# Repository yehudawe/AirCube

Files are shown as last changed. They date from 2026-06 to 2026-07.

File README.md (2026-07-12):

<p align="center">
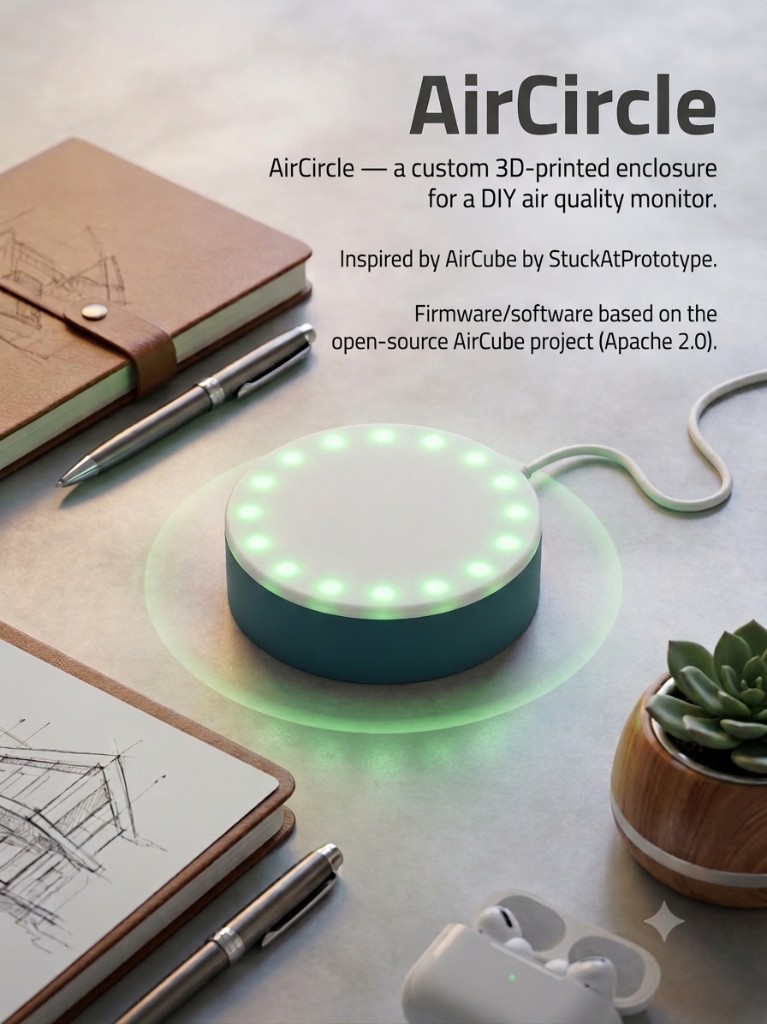
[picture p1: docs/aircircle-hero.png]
AirCircle — a custom 3D-printed DIY air quality monitor
  
</p>

# AirCircle

**A round, glowy DIY air monitor — built from AliExpress parts and a weekend of printing.**

AirCircle is a my remix of [AirCube](https://github.com/StuckAtPrototype/AirCube) by [StuckAtPrototype](https://stuckatprototype.com). Same idea: one LED ring tells you how the air feels, and Zigbee feeds the numbers into Home Assistant. Different hardware: an ESP32-H2 SuperMini, off-the-shelf sensors, and a 3D-printed puck you can build yourself.

This is a **personal fork**, not the official AirCube. Think of it as the breadboard cousin of the real thing — a bit scrappier, still pretty handy on a desk.

| | |
|---|---|
| **Printables** | [AirCircle enclosure STLs](https://www.printables.com/model/1779452-aircircle-diy-air-quality-monitor-enclosure) |
| **Upstream project** | [StuckAtPrototype/AirCube](https://github.com/StuckAtPrototype/AirCube) |
| **License** | [Apache 2.0](LICENSE) |
| **Extra build notes** | [DIY_SUPERMINI.md](DIY_SUPERMINI.md) |

> **Not affiliated with or endorsed by StuckAtPrototype.**

---

## What's in this repo

- **AirCircle enclosure** — a round, snap-together case (`mechanical/air-circle/`)
- **SuperMini firmware** — pin map in `firmware/main/board_config.h`
- **ENS160 + AHT21** sensors (the AliExpress-friendly combo)
- **WS2812 LED ring** on GPIO4 — green when life is good, red when you should open a window
- **Full build guide** — source the parts, print, wire, flash

You still get USB serial readings and **Zigbee / Home Assistant** support from the original AirCube firmware.

---

## What you need

### Electronics

Example AliExpress listings — double-check you pick the right variant:

| Part | Notes | Link |
|---|---|---|
| **ESP32-H2 SuperMini** | Must be the **H2** variant (Zigbee-capable) | [AliExpress](https://a.aliexpress.com/_c4Pyot8F) |
| **ENS160 + AHT21 module** | Combined gas + temperature/humidity sensor | [AliExpress](https://a.aliexpress.com/_c32NbwfH) |
| **WS2812 RGB LED ring** | Match LED count to your ring (e.g. 16-LED) | [AliExpress](https://a.aliexpress.com/_c4Vc3oaj) |

Plus a **USB data cable** for power and flashing.

### Fasteners

| Screw | Used for |
|---|---|
| **M3 × 4** | Sensor module → base |
| **M3 × 6** | ESP32-H2 SuperMini → base (via tab) |
| **M2** (short, for plastic) | LED ring → base *(optional, if the fit is loose)* |

The top cover fastens with screws at the printed mounting points on the base.

### 3D-printed parts

Download the STLs from **[Printables](https://www.printables.com/model/1779452-aircircle-diy-air-quality-monitor-enclosure)** or print from this repo:

| File | Purpose |
|---|---|
| `air_circ_base.stl` | Bottom shell |
| `air_circ_top.stl` | Translucent top cover — this is what makes the glow |
| `air_circ_lock.stl` | Tab — supports the ESP32-H2 in the base |
| `air_circle.stp` | Full assembly source (CAD edits) |

Original StuckAtPrototype enclosure files are in [`mechanical/original/`](mechanical/original/) for reference.

---

## Step 1 — Print the enclosure

1. Slice the three STL files in your slicer of choice.
2. **Material:** PLA or PETG. PETG handles a bit more warmth near the electronics.
3. **Top cover:** translucent or natural filament — that's the whole vibe.
4. **Orientation:** flat on the bed, largest face down. Supports only if your slicer insists.
5. Dry-fit base + top + lock before you start soldering.

Wrong ring size? Scale the STLs or tweak `air_circle.stp`.

---

## Step 2 — Wire and solder

Solder (or tightly twist-and-tape) the connections below before mounting anything in the enclosure. All logic signals are **3.3 V** — don't put 5 V on the sensor data lines or the LED data pin.

| Module pin | Connect to ESP32-H2 SuperMini |
|---|---|
| SDA | **GPIO1** (IO1) |
| SCL | **GPIO0** (IO0) |
| VCC | **3V3** |
| GND | **GND** |
| LED DIN | **GPIO4** (IO4) |
| LED +5V | **5V** (USB) — only if your ring needs 5 V power |
| LED GND | **GND** |

Both ENS160 (`0x52`) and AHT21 (`0x38`) share the same I2C bus.

**Button (GPIO9):** short press cycles brightness, hold **3 seconds** for Zigbee pairing (blue flash).

```
  ENS160+AHT21          ESP32-H2 SuperMini          WS2812 ring
  ─────────────         ──────────────────          ───────────
  SDA  ───────────────► GPIO1
  SCL  ───────────────► GPIO0
  VCC  ───────────────► 3V3
  GND  ───────────────► GND ────────────────────► GND
                        GPIO4 ──────────────────► DIN
                        5V (optional) ──────────► +5V
```

Pins: [`firmware/main/board_config.h`](firmware/main/board_config.h)

Double-check your joints, then trim any excess wire so nothing shorts once everything is packed inside the base.

---

## Step 3 — Assemble the enclosure

<p align="center">
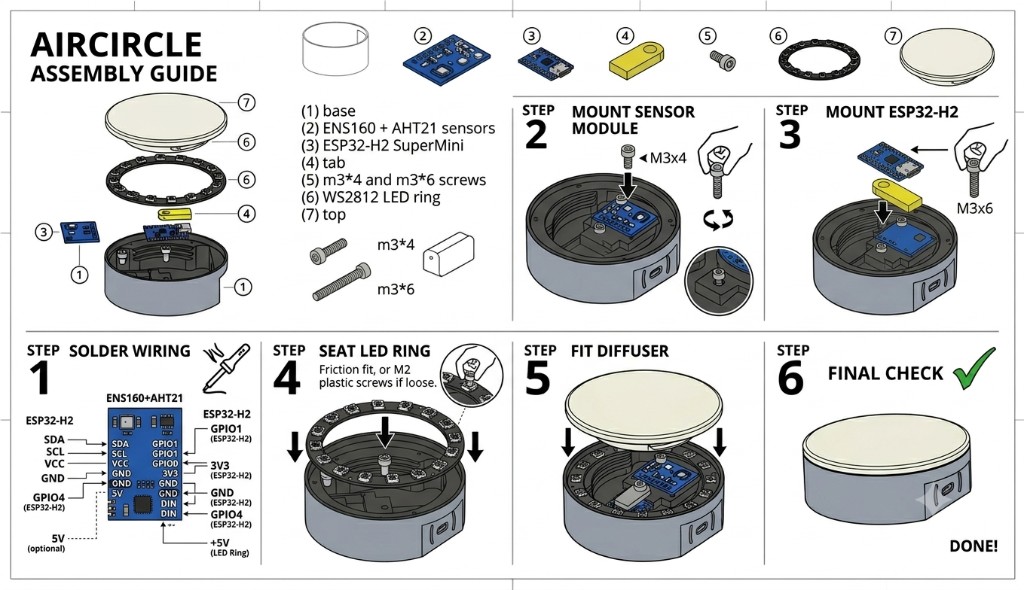
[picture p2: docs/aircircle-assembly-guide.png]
AirCircle assembly guide — wiring, mounting, and final assembly
  
</p>

With the wiring done, mount the parts into the printed base and close it up.

1. **Sensor module** — place the ENS160 + AHT21 board in the base slot and secure it with an **M3 × 4** screw.
2. **Tab + ESP32-H2** — insert the printed tab (`air_circ_lock.stl`) into the base, set the SuperMini on top with the USB-C port lined up to the base cutout, and fasten with an **M3 × 6** screw.
3. **LED ring** — seat the WS2812 ring on the inner rim of the base. A snug print should hold it by friction. If it feels loose, add **small M2 screws for plastic**.
4. **Top cover** — fit the translucent diffuser over the ring and screw it onto the base.

Done — plug in USB, flash if you haven't already, and let it warm up.

> **Tip:** Flash the firmware before screwing on the top cover — USB access and the boot button are much easier to reach.

---

## Step 4 — Configure LED count

Set the LED count to match your ring before building.

Edit [`firmware/main/ws2812_control.h`](firmware/main/ws2812_control.h):

```c
#define NUM_LEDS  16   // change to match your WS2812 ring or strip
```

Default is **30**; a 16-LED ring wants **16**.

---

## Step 5 — Build and flash firmware

Requires [ESP-IDF v5.3+](https://docs.espressif.com/projects/esp-idf/en/latest/esp32h2/get-started/).

```powershell
cd firmware
idf.py set-target esp32h2
idf.py build
idf.py -p COM9 flash monitor
```

Swap `COM9` for your port (`COM*` on Windows, `/dev/tty*` on Linux).

Give it **~3 minutes** after first boot for the ENS160 to warm up — patience, then the readings settle.

### Button controls

| Action | Result |
|---|---|
| Short press | Cycle brightness (off → 10% → 30% → 60% → 100%) |
| Hold 3 seconds | Zigbee pairing mode (blue flash) |

---

## Step 6 — View live readings (optional)

Plug in with a data-capable USB cable:

```powershell
cd scripts
pip install -r requirements.txt
python aircube_app.py
```

Pick your COM port, hit **Connect**, and watch the numbers roll in after warm-up.

---

## Home Assistant (optional)

AirCircle inherits AirCube's **Zigbee** stack. Pair with ZHA or Zigbee2MQTT:

**[HOME_ASSISTANT.md](HOME_ASSISTANT.md)**

Hold the boot button for 3 seconds, enable permit join on your coordinator, and you're in.

---

## How this differs from official AirCube

| | Official AirCube | AirCircle (this repo) |
|---|---|---|
| Board | Custom PCB | ESP32-H2 SuperMini |
| Gas sensor | ENS161 | ENS160 |
| Temp/humidity | ENS210 | AHT21 |
| LED | Onboard WS2812 | External WS2812 ring on GPIO4 |
| Enclosure | StuckAtPrototype design | 3D-printed AirCircle puck |
| BLE BTHome | Supported | Disabled in this fork's defaults |
| AQI-S score | Available over USB serial | Not available (`-1` on ENS160) |

Want the polished commercial version? Head to **[StuckAtPrototype/AirCube](https://github.com/StuckAtPrototype/AirCube)**.

---

## LED colors

The ring runs a smooth green-to-red gradient from **VOC Level** (TVOC-derived):

| LED color | Air quality |
|---|---|
| Green | Good |
| Yellow | Moderate |
| Orange | Poor |
| Red | Time to ventilate |
| Flashing blue | Zigbee pairing |

Full band tables live in the [upstream LED reference](https://github.com/StuckAtPrototype/AirCube/blob/master/README.md#led-reference).

---

## Troubleshooting

**No serial port detected**
- Use a data USB cable, not charge-only.
- Windows: try the [Silicon Labs USB-UART drivers](https://www.silabs.com/developers/usb-to-uart-bridge-vcp-drivers).

**Readings look off right after power-on**
- Normal. ~3 minutes warm-up for the ENS160.

**LED ring wrong or incomplete**
- Check `NUM_LEDS` matches your ring.
- DIN on **GPIO4**, shared GND.

**Zigbee won't pair**
- Hold boot button 3 seconds (blue flash).
- Enable permit join in ZHA or Zigbee2MQTT.
- Move closer to the coordinator.

**Home Assistant missing sensors**
- Load the ZHA quirk or Zigbee2MQTT converter — see [HOME_ASSISTANT.md](HOME_ASSISTANT.md).

---

## Repository layout

```
AirCircle/
├── docs/
│   ├── aircircle-hero.png           # Cover image
│   └── aircircle-assembly-guide.png # Visual assembly guide
├── mechanical/
│   ├── air-circle/          # AirCircle enclosure (STL + STEP)
│   └── original/            # Upstream reference enclosure files
├── firmware/                # Adapted ESP-IDF firmware
│   └── main/
│       ├── board_config.h   # SuperMini pin map
│       └── ws2812_control.h # LED count (NUM_LEDS)
├── scripts/                 # Desktop app for USB serial
├── DIY_SUPERMINI.md         # Supplementary build notes
└── HOME_ASSISTANT.md        # Zigbee setup (from upstream)
```

---

## License and attribution

Based on [AirCube](https://github.com/StuckAtPrototype/AirCube) by StuckAtPrototype, licensed under [Apache 2.0](LICENSE).

AirCircle mechanical files and SuperMini adaptations are shared under the same license. Keep the credit and license when you share or remix.

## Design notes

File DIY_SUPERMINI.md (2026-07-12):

# DIY Build — ESP32-H2 SuperMini

AirCube firmware adapted for breadboard builds with an **ENS160 + AHT21** sensor module and an external **WS2812 LED ring or strip**.

## Parts

Example AliExpress listings for a DIY build (not affiliated with StuckAtPrototype):

| Part | Notes | Link |
|---|---|---|
| **ESP32-H2 SuperMini** | Select the **H2** variant from the listing | [AliExpress](https://a.aliexpress.com/_c4Pyot8F) |
| **ENS160 + AHT21 sensor module** | Combined air-quality and temp/humidity board | [AliExpress](https://a.aliexpress.com/_c32NbwfH) |
| **WS2812 RGB LED ring** | Pick a ring size that fits your enclosure (e.g. 16-LED) | [AliExpress](https://a.aliexpress.com/_c4Vc3oaj) |

You also need a USB cable for power/data. Print the **AirCircle** enclosure from [Printables](https://www.printables.com/model/1779452-aircircle-diy-air-quality-monitor-enclosure) or use the STLs in `mechanical/air-circle/`.

### Fasteners

| Screw | Used for |
|---|---|
| **M3 × 4** | Sensor module → base |
| **M3 × 6** | ESP32-H2 SuperMini → base (via tab) |
| **M2** (short, for plastic) | LED ring → base *(optional)* |

## Wiring and soldering

Solder the connections below before mounting parts in the enclosure.

| Module pin | Connect to ESP32-H2 SuperMini |
|---|---|
| SDA | **GPIO1** (IO1) |
| SCL | **GPIO0** (IO0) |
| VCC | **3V3** |
| GND | **GND** |
| LED DIN | **GPIO4** (IO4) |
| LED +5V | **5V** (USB) if your strip needs 5 V |
| LED GND | **GND** |

Both ENS160 (0x52) and AHT21 (0x38) share the same I2C bus.

**Boot button (GPIO9):** short press cycles LED brightness; hold **3 seconds** for Zigbee pairing (blue flash).

## Assembly

<p align="center">
  AirCircle assembly guide
</p>

1. **Sensor module** — mount in the base with an **M3 × 4** screw.
2. **Tab + ESP32-H2** — insert the printed tab (`air_circ_lock.stl`), place the SuperMini on top (USB-C aligned to the cutout), secure with an **M3 × 6** screw.
3. **LED ring** — seat on the base rim. If the friction fit is loose, use **small M2 screws for plastic**.
4. **Top cover** — fit the diffuser and screw onto the base. Done.

Full step-by-step with printing and flashing: **[README.md](README.md)**.

## LED count

Edit `firmware/main/ws2812_control.h` and change `NUM_LEDS` to match your ring or strip (default **30**; use **16** for a 16-LED ring).

## Build and flash

Requires [ESP-IDF v5.3+](https://docs.espressif.com/projects/esp-idf/en/latest/esp32/get-started/).

```powershell
cd firmware
idf.py set-target esp32h2
idf.py build
idf.py -p COM9 flash monitor
```

## Desktop app

```powershell
cd scripts
pip install -r requirements.txt
python aircube_app.py
```

Select **COM9**, click **Connect** — live temp, humidity, eCO2, TVOC, and VOC Level appear after ~3 minutes warm-up.

## Notes

- **ENS160** is used instead of the official ENS161; AQI-S (relative score) is not available and shows as `-1` over serial.
- **AHT21** replaces the ENS210; temperature/humidity compensation for the gas sensor still works.
- Onboard **GPIO8** WS2812 is unused; the external strip on GPIO4 drives the air-quality color.

Pin definitions live in `firmware/main/board_config.h`.

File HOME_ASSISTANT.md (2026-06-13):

# Connecting AirCube to Home Assistant

This guide walks you through adding your AirCube air quality monitor to Home Assistant over Zigbee. After setup, you'll have live temperature, humidity, eCO2, eTVOC, and VOC Level readings plus a brightness slider in your smart home dashboard.

The AirCube works with both **ZHA** (built-in) and **Zigbee2MQTT**. Pick whichever you already use. If you're starting fresh, ZHA is simpler.

---

## What You Need

- **AirCube** -- powered via USB-C
- **Zigbee coordinator dongle** -- plugs into your Home Assistant machine
- **Home Assistant** -- running on any supported hardware (Raspberry Pi, mini PC, etc.)

### Recommended Zigbee Coordinators

Any Zigbee 3.0 coordinator works. If you don't have one yet, the **SONOFF ZBDongle-E** is the easiest to get started with (~$13).

| Dongle | Notes |
|---|---|
| SONOFF ZBDongle-E | Best value, widely available |
| SONOFF ZBDongle-P | Proven, large community |
| ConBee II / III | Also works, popular alternative |

---

# Method A -- ZHA (Recommended)

Use this method if you're using Home Assistant's built-in **Zigbee Home Automation** integration (the default). No extra add-ons required.

## A1 -- Set Up ZHA

If you already have ZHA running with your coordinator, skip to A2.

1. Plug your Zigbee coordinator dongle into your Home Assistant machine.
2. Go to **Settings > Devices & Services > Add Integration**.
3. Search for **Zigbee Home Automation (ZHA)** and add it.
4. Select your coordinator from the serial port list and follow the prompts.

## A2 -- Add the AirCube Quirk

The AirCube uses a custom Zigbee cluster (0xFC01) for air quality data and a standard Analog Output cluster (0x000D) for LED brightness. The quirk below tells ZHA to create **sensor entities** for eCO2, eTVOC, and VOC Level, plus a **brightness slider** (0--100%).

1. Install the **File editor** add-on if you don't have it:
   - **Settings > Add-ons > Add-on Store** -- search **File editor**, install, start it.

2. Open **File editor** from the sidebar.

3. Create a folder called **`custom_zha_quirks`** **next to your `configuration.yaml`**.

   > **Where do I create it?** Open the File editor and look for `configuration.yaml`. On **HA 2026.x** it's in `/homeassistant/`, on **HA 2025.x and earlier** it's in `/config/`. Create `custom_zha_quirks` in whichever folder contains your `configuration.yaml`. **Do not** create a new folder called `config` -- just put `custom_zha_quirks` directly alongside `configuration.yaml`.

4. Inside `custom_zha_quirks`, create a new file called **`aircube.py`** and paste this content:

```python
"""StuckAtPrototype AirCube air quality monitor quirk for ZHA."""

from zigpy.quirks import CustomCluster
from zigpy.quirks.v2 import QuirkBuilder
from zigpy.quirks.v2.homeassistant import EntityType
from zigpy.zcl.foundation import ZCLAttributeDef
import zigpy.types as t

try:
    from zigpy.quirks.v2.homeassistant.sensor import SensorDeviceClass, SensorStateClass
except ImportError:
    from homeassistant.components.sensor import SensorDeviceClass, SensorStateClass

class AirQualityCluster(CustomCluster):
    """AirCube custom air quality cluster (0xFC01) — read-only sensors."""

    cluster_id = 0xFC01
    name = "AirCube Air Quality"
    ep_attribute = "aircube_air_quality"

    class AttributeDefs(CustomCluster.AttributeDefs):
        eco2 = ZCLAttributeDef(
            id=0x0000, type=t.uint16_t, is_manufacturer_specific=False
        )
        etvoc = ZCLAttributeDef(
            id=0x0001, type=t.uint16_t, is_manufacturer_specific=False
        )
        aqi = ZCLAttributeDef(
            id=0x0002, type=t.uint16_t, is_manufacturer_specific=False
        )

ANALOG_OUTPUT_CLUSTER_ID = 0x000D

(
    QuirkBuilder("StuckAtPrototype", "AirCube")
    .replaces(AirQualityCluster, endpoint_id=10)
    .sensor(
        AirQualityCluster.AttributeDefs.eco2.name,
        AirQualityCluster.cluster_id,
        endpoint_id=10,
        unit="ppm",
        translation_key="equivalent_co2",
        state_class=SensorStateClass.MEASUREMENT,
        fallback_name="Equivalent CO2",
    )
    .sensor(
        AirQualityCluster.AttributeDefs.etvoc.name,
        AirQualityCluster.cluster_id,
        endpoint_id=10,
        unit="ppb",
        device_class=SensorDeviceClass.VOLATILE_ORGANIC_COMPOUNDS_PARTS,
        state_class=SensorStateClass.MEASUREMENT,
        fallback_name="tVOC",
    )
    .sensor(
        AirQualityCluster.AttributeDefs.aqi.name,
        AirQualityCluster.cluster_id,
        endpoint_id=10,
        device_class=SensorDeviceClass.AQI,
        state_class=SensorStateClass.MEASUREMENT,
        fallback_name="VOC Level (TVOC)",
    )
    .number(
        "present_value",
        ANALOG_OUTPUT_CLUSTER_ID,
        endpoint_id=10,
        min_value=0,
        max_value=100,
        step=1,
        mode="slider",
        entity_type=EntityType.STANDARD,
        translation_key="brightness",
        fallback_name="Brightness",
    )
    .add_to_registry()
)
```

5. Open your main **`configuration.yaml`** (in `/config/`) and add:

   ```yaml
   zha:
     custom_quirks_path: /config/custom_zha_quirks/
     enable_quirks: true
   ```

   > **Note:** Use `/config/custom_zha_quirks/` exactly as shown -- this path works on **both** HA 2025.x and 2026.x, even though the File editor in 2026.x shows the root as `/homeassistant/`. The trailing `/` is required on HA 2026.x. **Do not** change `/config/` to `/homeassistant/` in this setting.

   If you already have a `zha:` section, just add the two lines underneath it.

6. **Restart Home Assistant** from **Settings > System > Restart**.
7. **Remove and re-pair** the AirCube once after adding the quirk (ZHA caches device data at first join).

## A3 -- Pair the AirCube

1. Go to **Settings > Devices & Services > ZHA**.
2. Click **Add Device**.
3. **Plug in your AirCube** via USB-C. On first power-up, it automatically enters pairing mode.

   > **Already plugged in?** Hold the button on the AirCube for **3 seconds**. The LEDs will start flashing blue.

4. Wait 10-30 seconds. The AirCube will appear in ZHA. Give it a name like `AirCube Living Room`.

5. When the LEDs stop flashing blue and return to a steady color, pairing is complete.

## A4 -- Verify Sensors

Go to **Settings > Devices & Services > ZHA** and click on the AirCube device. You should see six entities:

| Entity | What It Does | Unit |
|---|---|---|
| Temperature | Room temperature | C |
| Humidity | Relative humidity | % |
| Equivalent CO2 | eCO2 concentration (estimated) | ppm |
| tVOC | eTVOC concentration | ppb |
| VOC Level (TVOC) | TVOC-derived VOC Level (0--500) | -- |
| Brightness | LED brightness (slider) | 0--100 |

> Temperature and humidity are detected automatically by ZHA. eCO2, eTVOC, and VOC Level come from the custom quirk. The brightness slider uses the standard Analog Output cluster.

---

# Method B -- Zigbee2MQTT

Use this method if you prefer Zigbee2MQTT or already have it running.

## B1 -- Install MQTT Broker

1. Go to **Settings > Add-ons > Add-on Store**.
2. Search for **Mosquitto broker**, click **Install**, then **Start**.
3. Go to **Settings > Devices & Services > Add Integration**.
4. Search for **MQTT** and add it. Accept the defaults.

## B2 -- Install Zigbee2MQTT

1. Go to **Settings > Add-ons > Add-on Store**.
2. Click the **three-dot menu** (top-right) > **Repositories**.
3. Add this URL:
   ```
   https://github.com/zigbee2mqtt/hassio-zigbee2mqtt
   ```
4. Search for **Zigbee2MQTT** and click **Install**.

## B3 -- Plug In Your Coordinator

1. Plug the Zigbee dongle into your Home Assistant machine.
2. Go to **Settings > System > Hardware** > three-dot menu > **All Hardware**.
3. Find your dongle. Write down its path (e.g. `/dev/ttyACM0`).

## B4 -- Configure and Start Zigbee2MQTT

1. Go to **Settings > Add-ons > Zigbee2MQTT > Configuration** tab.
2. Set the serial port:
   ```yaml
   serial:
     port: /dev/ttyACM0
   ```
3. Enable **Start on boot** and **Watchdog**, then click **Start**.

## B5 -- Add the AirCube Converter

The converter file format depends on your Zigbee2MQTT version:
- **Z2M 2.x** (2024+): Uses ES modules (`.mjs`)
- **Z2M 1.x** (legacy): Uses CommonJS (`.js`)

Both converter files are in the [`z2m/`](z2m/) folder of this repo.

### Z2M 2.x (Recommended)

1. Open **File editor** (install from Add-on Store if needed).
2. Navigate to the `zigbee2mqtt` folder and create an `external_converters` subfolder.
3. Copy [`z2m/aircube.mjs`](z2m/aircube.mjs) into the `external_converters` folder.
4. Open **`configuration.yaml`** in the `zigbee2mqtt` folder and add:

   ```yaml
   external_converters:
     - external_converters/aircube.mjs
   ```

5. **Restart Zigbee2MQTT** from the add-on page.

### Z2M 1.x (Legacy)

1. Open **File editor**.
2. Copy [`z2m/aircube.js`](z2m/aircube.js) into the `zigbee2mqtt` folder.
3. Open **`configuration.yaml`** in the `zigbee2mqtt` folder and add:

   ```yaml
   external_converters:
     - aircube.js
   ```

4. **Restart Zigbee2MQTT** from the add-on page.

## B6 -- Pair the AirCube

1. In the Zigbee2MQTT dashboard, click **Permit join (All)**.
2. **Plug in your AirCube** via USB-C (or hold the button 3 seconds if already plugged in).
3. Wait for the LEDs to stop flashing blue.
4. Name the device in Zigbee2MQTT (e.g. `AirCube Living Room`).

## B7 -- Verify Sensors

Go to **Settings > Devices & Services > MQTT** and click on the AirCube. You should see six entities: Temperature, Humidity, eCO2, eTVOC, VOC Level (TVOC-derived), and Brightness.

---

# Dashboard

These cards work with both ZHA and Zigbee2MQTT.

### Quick Entities Card

Edit your dashboard, click **Add Card**, choose **Entities**, and select:
- AirCube Temperature
- AirCube Humidity
- AirCube Equivalent CO2
- AirCube tVOC
- AirCube VOC Level (TVOC)
- AirCube Brightness

### VOC Level Gauge

Add a **Manual card** and paste:

```yaml
type: gauge
entity: sensor.aircube_living_room_air_quality_index
name: Air Quality
min: 0
max: 500
severity:
  green: 0
  yellow: 50
  red: 200
```

### 24-Hour History

```yaml
type: history-graph
title: Air Quality - Last 24 Hours
hours_to_show: 24
entities:
  - entity: sensor.aircube_living_room_temperature
  - entity: sensor.aircube_living_room_humidity
  - entity: sensor.aircube_living_room_air_quality_index
```

> Entity names depend on what you named the device. Check **Settings > Devices & Services** for the exact entity IDs.

---

## LED Reference

The LED follows **canonical VOC Level** (TVOC-derived) on a continuous green-to-red gradient. The hue moves linearly with VOC Level, so the color fades smoothly rather than stepping between bands. eCO2 does **not** affect the LED.

| LED color | VOC Level | TVOC (ppb) | Rating |
|---|-----|---|---|
| Steady green | 0--10 | 0--~43 | Excellent |
| Green → lime | 10--50 | ~43--220 | Good |
| Lime → yellow | 50--100 | 220--650 | Moderate |
| Yellow → orange → red | 100--200 | 650--2,200 | Poor |
| Steady red | 200+ | 2,200+ | Unhealthy |
| Flashing blue | -- | -- | Pairing mode (searching for Zigbee network) |
| Off | -- | -- | Brightness set to 0 (press button to cycle) |

> On firmware **1.4.3 and below**, the same gradient was driven by **AQI-S** (relative) instead of canonical VOC Level. See the [README LED Reference](README.md#led-reference) for the full mapping.

### Button

| Action | Result |
|---|---|
| Short press | Cycle LED brightness (off, 10%, 30%, 60%, 100%) |
| Hold 3 seconds | Enter Zigbee pairing mode (LEDs flash blue) |

---

## Troubleshooting

### The AirCube LEDs flash blue but it never connects

- Make sure pairing/permit join is enabled in ZHA or Zigbee2MQTT.
- Move the AirCube closer to the coordinator. Zigbee works best within 10-30 meters indoors.
- Check that your coordinator is online in the integration dashboard.

### Temperature and humidity show up but eCO2 / eTVOC / VOC Level are missing

- The custom quirk (ZHA) or converter (Z2M) is not loaded.
- **ZHA:** Check that `custom_quirks_path` is set in `configuration.yaml` and the `aircube.py` file is in the right folder. The path in `configuration.yaml` must be `/config/custom_zha_quirks/` (not `/homeassistant/...`). Restart Home Assistant, then remove and re-pair the AirCube.
- **ZHA (HA 2026.x):** The File editor shows the root as `/homeassistant/` instead of `/config/`. **Do not** create a new folder called `config` inside `/homeassistant/`. Place `custom_zha_quirks` directly inside `/homeassistant/`, next to `configuration.yaml`. The path in `configuration.yaml` should still say `/config/custom_zha_quirks/`.
- **Firmware:** Make sure you are running the latest AirCube firmware from this repo. It actively sends attribute reports for the custom cluster so ZHA updates the sensors.
- **Firmware version:** The device reports its build as the Zigbee Basic cluster **Software build ID** (`sw_build_id`, attribute `0x4000` on cluster `0x0000`, endpoint `10`). In ZHA you can read it under the device’s **Manage Zigbee device** UI. The string comes from ESP-IDF’s app version (`firmware/version.txt` at build time).
- **Z2M 2.x:** Make sure you're using `aircube.mjs` (not `aircube.js`). Z2M 2.x requires ES module format. If Z2M renames the file to `aircube.mjs.invalid`, the converter has a load error — check the Z2M logs.
- **Z2M 1.x:** Check that `external_converters` is in the Z2M `configuration.yaml` and `aircube.js` is in the `zigbee2mqtt` folder. Restart Zigbee2MQTT.

### eCO2 / eTVOC / VOC Level values are stuck at 0

This is normal for the first 5 minutes after power-on. The air quality sensor needs to warm up. Once ready, values will start updating (typically within 60 seconds).

### I want to pair the AirCube to a different Home Assistant

Hold the button for 3 seconds to re-enter pairing mode. If the device won't leave its old network, unplug it, plug it back in, and immediately hold the button for 3 seconds while it boots.

### Sensor values only update every 10 seconds

This is by design. The AirCube pushes new sensor values over Zigbee every 10 seconds. Additionally, the ZCL reporting configuration will send an immediate update when a reading changes significantly (temperature by 0.5 C, eCO2 by 50 ppm, VOC Level by 5 points, etc.).

### Can I use multiple AirCubes?

Yes. The quirk/converter applies to every AirCube automatically. Just pair each one and give it a unique name. Each gets its own set of sensors and brightness control.

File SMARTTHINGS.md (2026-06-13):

# Connecting AirCube to SmartThings (Samsung hub)

This guide walks you through pairing AirCube to a **SmartThings-compatible Zigbee hub** and installing the community **AirCube Zigbee** Edge driver so you get **temperature, humidity, eCO2, eTVOC, and VOC Level** in the SmartThings app.

> **Default behavior:** Without this driver, SmartThings often joins AirCube as a generic **humidity / temperature** device. You only get **temp and humidity**. The Edge driver adds the **air quality** sensors over Zigbee cluster `0xFC01` (same idea as the [ZHA quirk](zha/aircube.py) and [Zigbee2MQTT converter](z2m/aircube.js)).

**You will need**

- AirCube powered over USB-C
- A **SmartThings Edge**–capable hub (e.g. SmartThings v3, Aeotec Smart Home Hub, SmartThings Station) on your Samsung account
- A **Mac, Windows, or Linux PC** for the [SmartThings CLI](https://github.com/SmartThingsCommunity/smartthings-cli) (one-time driver install)
- A [Samsung account](https://account.samsung.com/) used with SmartThings

The first time the CLI needs your SmartThings account, it **starts a browser sign-in** automatically (you may not see a separate `login` subcommand in `smartthings --help`). You do **not** need to create a Personal Access Token in the developer portal for normal interactive use. For **automation / CI**, you can use a [PAT](https://developer.smartthings.com/docs/personal-access-tokens) with channel scopes — see [driver channels](https://developer.smartthings.com/docs/devices/hub-connected/driver-channels).

---

## Step 1 — Put AirCube in pairing mode

1. Plug in AirCube (or, if already powered, use the next step).
2. **Hold the button for about 3 seconds** until the LEDs **flash blue** (Zigbee pairing mode).

See the [README](README.md) LED / button table if you need a refresher.

---

## Step 2 — Add AirCube in the SmartThings mobile app

1. Open the **SmartThings** app → **Add device** (or **+**).
2. Choose **Scan nearby** / **Zigbee** / **Generic Zigbee device** per your app version, and enable **pairing** on the hub when prompted.
3. Wait until AirCube appears and finish naming / room assignment.

**Check:** Open the new device — you should see **temperature** and **humidity**.  
**eCO2, TVOC, and VOC Level will not appear yet** until the **AirCube Zigbee** driver is installed and selected (next steps).

---

## Step 3 — Install the SmartThings CLI (sign-in is automatic)

1. Install the CLI using the [official instructions](https://github.com/SmartThingsCommunity/smartthings-cli) for your OS (Homebrew on Mac: `brew install smartthings`).
2. Run `smartthings --version` and confirm the command works.

**Authentication:** Many recent builds do **not** list a `smartthings login` command. The **first command that calls the SmartThings API** (for example **`smartthings edge:drivers:package .`** in Step 5) will **open a browser** so you can sign in with your Samsung account. Complete that flow once; later CLI commands reuse the session.

- To **sign out** on this machine: `smartthings logout` (then the next API command will prompt for login again).
- **Optional:** Headless or automation-only setups can use a **Personal Access Token** instead; see [CLI authentication](https://developer.smartthings.com/docs/sdks/cli/).

---

## Step 4 — Get the Edge driver source

From your clone of **this repository** (folder name may differ):

```bash
cd smartthings/aircube-zigbee
```

If you have not cloned yet:

```bash
git clone https://github.com/StuckAtPrototype/AirCube.git
cd AirCube/smartthings/aircube-zigbee
```

That directory contains `config.yml`, `fingerprints.yml`, `profiles/`, and `src/init.lua`.

---

## Step 5 — Package the driver (build + upload)

From `smartthings/aircube-zigbee`:

```bash
smartthings edge:drivers:package .
```

The **first** time you run this (or any API command), the CLI may **open the browser** for Samsung sign-in — complete it, then re-run `package` if needed.

The CLI prints a **Driver Id** and **Version** (timestamp string). **Save both** — you need them to assign the driver to a channel.

Optional: also write a local zip:

```bash
smartthings edge:drivers:package . -b ./aircube-zigbee.zip
```

> Recent CLI versions **upload** the driver when you package; there is **no** separate `publish` command.

---

## Step 6 — Create a driver channel (first time only)

You need a **driver channel** to install your own driver on the hub.

This repo ships [`smartthings/driver-channel.json`](smartthings/driver-channel.json) for `edge:channels:create`. It points **`termsOfServiceUrl`** at the StuckAtPrototype **[Terms of Service](https://stuckatprototype.com/policies/terms-of-service)**. Edit **`name`** / **`description`** in that file if you want different labels on your channel.

From the **repository root** (the folder that contains `smartthings/`):

```bash
smartthings edge:channels:create -i smartthings/driver-channel.json
```

List channels and copy your **channel id** (UUID):

```bash
smartthings edge:channels
```

---

## Step 7 — Assign the packaged driver to your channel

```bash
smartthings edge:channels:assign <DRIVER_ID> "<VERSION>" --channel <CHANNEL_ID>
```

Use the **Driver Id** and **Version** from Step 5. You can omit arguments and use **interactive prompts** instead.

---

## Step 8 — Enroll your hub, then install the driver

**Order matters:** enroll the hub on the channel **before** install.

```bash
smartthings edge:channels:enroll --channel <CHANNEL_ID>
```

Pick your hub when prompted (or pass flags if your CLI supports them).

Then install the driver **onto that hub** from the same channel:

```bash
smartthings edge:drivers:install --channel <CHANNEL_ID> --hub <HUB_DEVICE_UUID>
```

### Hub id must be a UUID

`<HUB_DEVICE_UUID>` looks like `xxxxxxxx-xxxx-xxxx-xxxx-xxxxxxxxxxxx`. It is **not** the sticker MAC, Zigbee EUI, or `networkId` string.

**Where to find it**

- [SmartThings Advanced Web App](https://my.smartthings.com/advanced) → open your **hub** as a device → copy **Device id**, **or**
- Open any Zigbee child device (e.g. AirCube) → **Parent device** / hub → copy that hub’s id.

If you omit `--hub`, the CLI usually offers a **list** — picking from the list avoids typos.

If install returns **HTTP 400**, see [Troubleshooting](#troubleshooting) below.

---

## Step 9 — Use the AirCube Zigbee driver for your device

The hub must run **AirCube Zigbee** instead of the generic **Zigbee Humidity Sensor** driver.

**Option A — Switch driver (keep device / room)**

```bash
smartthings edge:drivers:switch <DEVICE_ID>
```

Use the AirCube **device** id from the Advanced Web App (not the hub id). Follow prompts to select **AirCube Zigbee**.

**Option B — Remove and re-pair**

Remove AirCube from SmartThings, then add it again (Step 2) **after** the driver is installed on the hub. With a matching fingerprint, SmartThings should pick **AirCube Zigbee** automatically.

---

## Step 10 — Confirm in the Advanced Web App

1. Open [SmartThings Advanced Web App](https://my.smartthings.com/advanced).
2. Select **AirCube**.
3. Check **Driver** (or device summary): it should show **AirCube Zigbee** (or your packaged driver name), not only “Zigbee Humidity Sensor”.
4. Under capabilities / state, you should eventually see **carbon dioxide**, **TVOC**, and **air quality** style attributes after reports arrive (allow a few minutes for sensor warm-up).

---

## Step 11 — Confirm in the mobile app

Open the device card: you should see **temperature**, **humidity**, **CO₂**, **TVOC**, and **air quality** (labels may vary slightly by app version).

Gas sensors may read **0** for the first few minutes after power-on — that is normal while the ENS16x warms up (same as [Home Assistant](HOME_ASSISTANT.md)).

---

## Troubleshooting

| Problem | What to try |
|---|---|
| Only temp / humidity | Driver not applied — repeat [Step 9](#step-9--use-the-aircube-zigbee-driver-for-your-device). |
| `drivers:install` **400 Bad Request** | Use **hub UUID**, not sticker id. Run **`channels:enroll`** for the same channel first. |
| eCO2 / TVOC / VOC Level stuck at 0 | Wait **3–5+ minutes** after power-on. Ensure driver is **AirCube Zigbee** and hub is **online**. |
| CLI / channel errors | Run `smartthings logout` then repeat the command that triggered login (browser). If you use a **PAT** instead, confirm it includes **channel** read/write. See [driver channels](https://developer.smartthings.com/docs/devices/hub-connected/driver-channels). |

---

## Technical reference

Zigbee layout (endpoint **10**): standard temp/humidity clusters; custom air quality cluster **`0xFC01`**; LED brightness uses Analog Output **`0x000D`** (not exposed in this driver v1). Details match [CONTRIBUTING.md](CONTRIBUTING.md) → *Zigbee Integration*.

---

## Contributors

If you improve the Edge driver or this guide, open a **pull request** on the [AirCube](https://github.com/StuckAtPrototype/AirCube) repository so all users get the update.

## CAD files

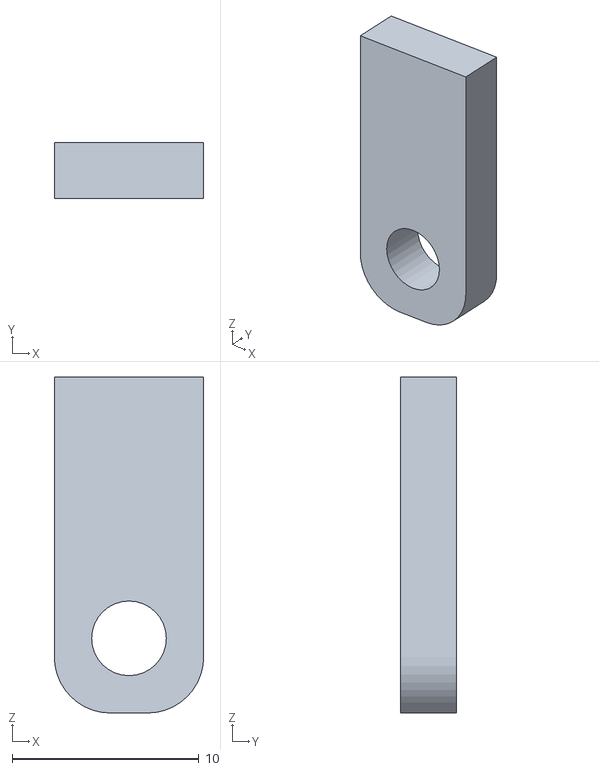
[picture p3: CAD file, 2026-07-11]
mechanical/air-circle/air_circ_lock.stl
8.00 x 3.00 x 18.0

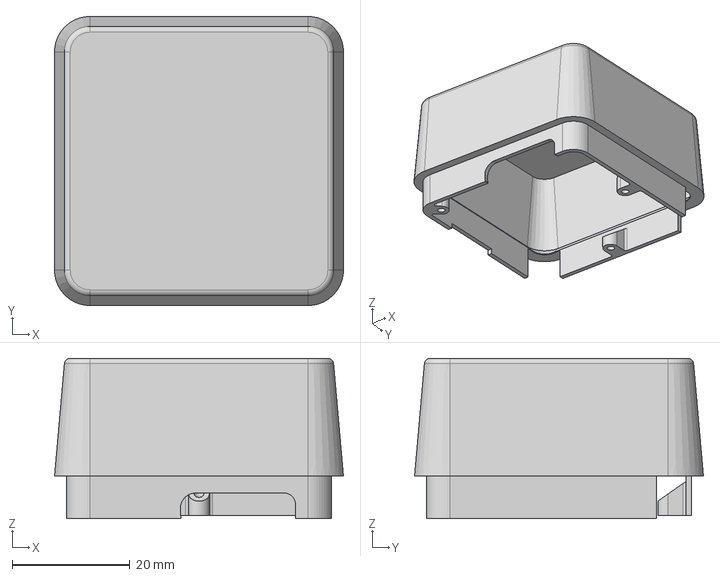
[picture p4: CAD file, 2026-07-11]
mechanical/original/AirCube top 20mm PROD.step
49.0 x 49.0 x 27.2 mm

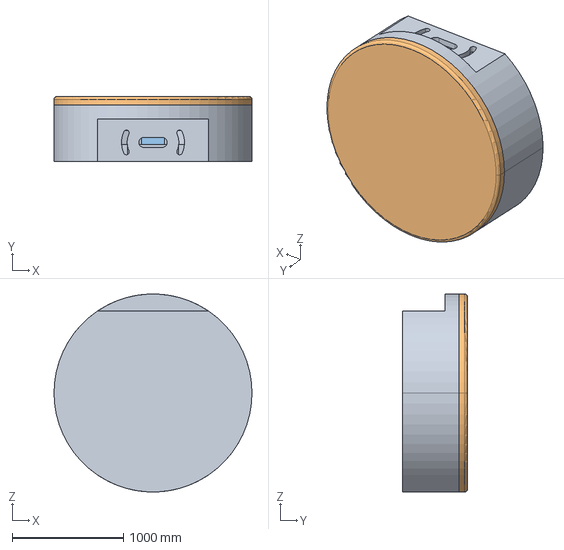
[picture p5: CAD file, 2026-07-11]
mechanical/air-circle/air_circle.stp
1778.0 x 584.2 x 1777.6 mm

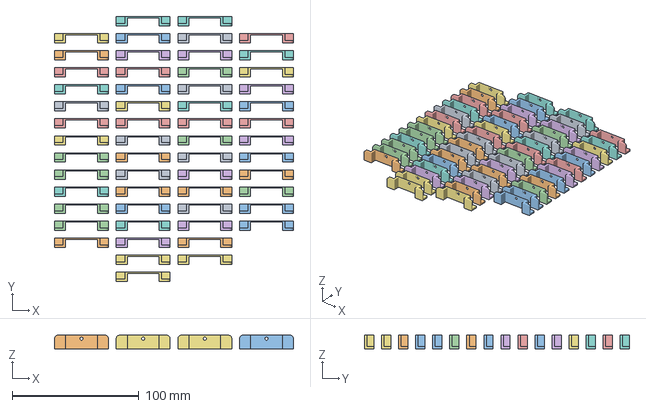
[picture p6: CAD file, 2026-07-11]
mechanical/original/AirCube air wall 11-7-43.3mf
188.4 x 208.9 x 10.8 mm
AirCube airwall v1.1 11-14-954.stl x 56

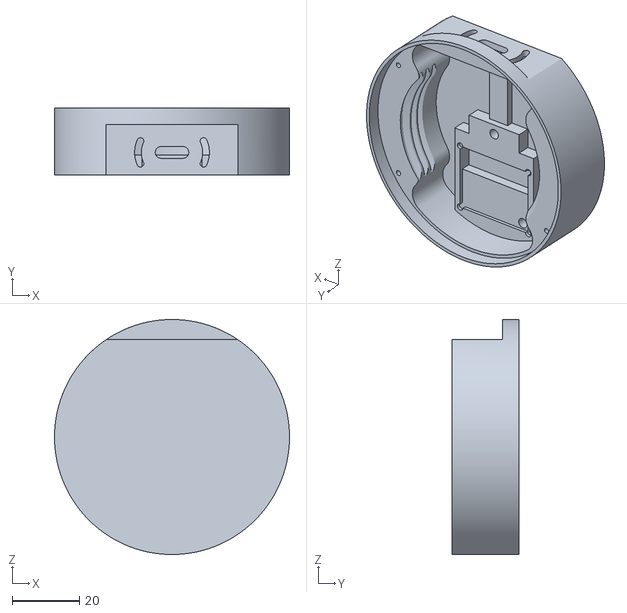
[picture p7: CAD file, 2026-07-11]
mechanical/air-circle/air_circ_base.stl
70.0 x 20.0 x 70.0

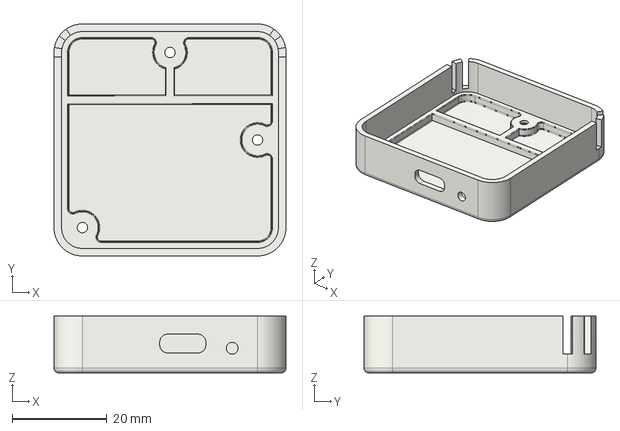
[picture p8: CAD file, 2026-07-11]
mechanical/original/AirCube bottom_prod_12-11.step
49.0 x 49.0 x 12.0 mm

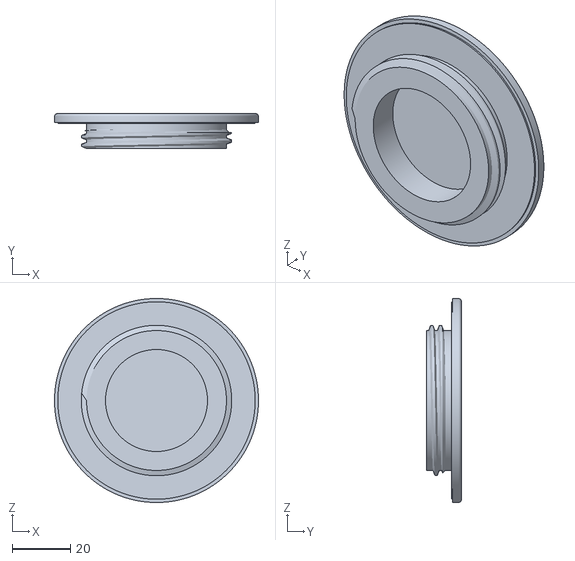
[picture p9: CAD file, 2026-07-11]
mechanical/air-circle/air_circ_top.stl
70.0 x 12.0 x 70.0

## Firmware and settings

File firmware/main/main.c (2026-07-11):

#include "freertos/FreeRTOS.h"
#include "freertos/task.h"
#include "freertos/semphr.h"
#include "esp_log.h"
#include "esp_pm.h"
#include "esp_task_wdt.h"
#include "nvs_flash.h"
#include "led_color_lib.h"

#include "led.h"
#include "ens210.h"
#include "ens16x_driver.h"
#include "i2c_driver.h"
#include "serial_protocol.h"
#include "button.h"
#include "history.h"
#include "zigbee.h"
#include "ble_bthome.h"

static const char *TAG = "main";

#define SENSOR_TASK_STACK_SIZE 4096
#define SENSOR_TASK_PRIORITY 5
#define COMMAND_TASK_STACK_SIZE 4096
#define COMMAND_TASK_PRIORITY 4

// Configurable sensor readout period (default 1000ms)
static uint32_t sensor_readout_period_ms = 1000;
static SemaphoreHandle_t readout_period_mutex = NULL;

// LED color mapping: continuous green->red gradient from canonical VOC Level (TVOC-derived).
#define AQI_MIN 0
#define AQI_MAX 200
#define AQI_GREEN_THRESHOLD 10  // Values 0-10 are pure green

#define HUE_GREEN  21845  // 120 deg - pure green

// VOC Level values at each TVOC band edge (matches published VOC table):
//   0-65 ppb      -> VOC Level 0-15   (Excellent)
//   65-220 ppb    -> VOC Level 15-50  (Good)
//   220-650 ppb   -> VOC Level 50-100 (Moderate)
//   650-2200 ppb  -> VOC Level 100-200 (Poor)
//   2200-5500 ppb -> VOC Level 200-500 (Unhealthy)
// Driven by TVOC alone; eCO2 is reported separately as raw ppm.
static const int AQI_TVOC_THRESHOLDS_PPB[5] = { 65, 220, 650, 2200, 5500 };
static const uint16_t BAND_AQI_TVOC[6] = {
    0,    // Level 0 - 0 ppb
    15,   // Level 1 - Excellent / Good edge   (65 ppb)
    50,   // Level 2 - Good / Moderate edge    (220 ppb)
    100,  // Level 3 - Moderate / Poor edge    (650 ppb)
    200,  // Level 4 - Poor / Unhealthy edge   (2200 ppb)
    500   // Level 5 - Unhealthy cap           (5500 ppb)
};

// Canonical VOC Level (TVOC-derived) for LED color mapping
static int current_aqi = 0;

// Static variables for smooth LED color transitions
static float current_hue = 21845.0f;  // Current hue value (21845 = green, 0 = red) - using float for smooth transitions
static uint16_t target_hue = 21845;   // Target hue value we want to transition to
#define TRANSITION_SPEED 0.02f  // Transition speed per update (0.0 to 1.0, higher = faster)
// With 20ms update interval and 0.02 speed, full transition takes ~1 second (50 steps)

// Getter and setter for sensor readout period (for serial_protocol.c)
uint32_t get_sensor_readout_period_ms(void)
{
    uint32_t period = 1000;
    if (readout_period_mutex != NULL) {
        if (xSemaphoreTake(readout_period_mutex, portMAX_DELAY) == pdTRUE) {
            period = sensor_readout_period_ms;
            xSemaphoreGive(readout_period_mutex);
        }
    }
    return period;
}

void set_sensor_readout_period_ms(uint32_t period)
{
    if (readout_period_mutex != NULL) {
        if (xSemaphoreTake(readout_period_mutex, portMAX_DELAY) == pdTRUE) {
            sensor_readout_period_ms = period;
            xSemaphoreGive(readout_period_mutex);
        }
    }
}

/**
 * @brief Map VOC Level value to hue
 * 
 * Maps canonical VOC Level (TVOC-derived, 0-500) to LED hue:
 * - VOC Level 0-10: pure green (no color change)
 * - VOC Level 10-200: smooth gradient from green to red
 * - VOC Level 200+: full red (handled by caller)
 * 
 * @param aqi VOC Level value
 * @return 16-bit hue value (21845 = green, 0 = red)
 */
static uint16_t aqi_to_hue(int aqi)
{
    // Clamp VOC Level to valid range
    if (aqi < AQI_MIN) aqi = AQI_MIN;
    if (aqi > AQI_MAX) aqi = AQI_MAX;
    
    // Values 0-10 are pure green
    if (aqi <= AQI_GREEN_THRESHOLD) {
        return HUE_GREEN;
    }
    
    // For values 10-200, map smoothly from green to red
    // Map VOC Level from [10, 200] to ratio [0.0, 1.0] for smooth gradient
    // When VOC Level = 10: ratio = 0.0 (green)
    // When VOC Level = 200: ratio = 1.0 (red)
    float ratio = (float)(aqi - AQI_GREEN_THRESHOLD) / (float)(AQI_MAX - AQI_GREEN_THRESHOLD);
    
    // Linear interpolation from green to red
    // ratio = 0.0 -> hue = HUE_GREEN (green)
    // ratio = 1.0 -> hue = 0 (red)
    uint16_t hue = HUE_GREEN - (uint16_t)(ratio * HUE_GREEN);
    
    return hue;
}

/**
 * @brief Map TVOC ppb to a continuous VOC Level position 0.0..5.0
 *
 * Uses AQI_TVOC_THRESHOLDS_PPB (65, 220, 650, 2200, 5500 ppb).
 */
static float aqi_tvoc_to_level_pos(int value)
{
    if (value <= 0) {
        return 0.0f;
    }
    if (value >= AQI_TVOC_THRESHOLDS_PPB[4]) {
        return 5.0f;
    }
    if (value < AQI_TVOC_THRESHOLDS_PPB[0]) {
        return (float)value / (float)AQI_TVOC_THRESHOLDS_PPB[0];
    }
    for (int i = 0; i < 4; i++) {
        if (value < AQI_TVOC_THRESHOLDS_PPB[i + 1]) {
            float span = (float)(AQI_TVOC_THRESHOLDS_PPB[i + 1] - AQI_TVOC_THRESHOLDS_PPB[i]);
            float frac = (float)(value - AQI_TVOC_THRESHOLDS_PPB[i]) / span;
            return (float)(i + 1) + frac;
        }
    }
    return 5.0f;
}

/**
 * @brief Compute the canonical AirCube VOC Level from TVOC.
 *
 * Maps TVOC ppb to VOC Level 0-500 using fixed indoor-air bands (see BAND_AQI_TVOC).
 * TVOC-only; eCO2 is reported separately. LED color follows this VOC Level via
 * aqi_to_hue() (green at 0-10, gradient to red at 200+).
 *
 * @param etvoc Equivalent TVOC in ppb
 * @return VOC Level value in [0, 500]
 */
static uint16_t aqi_calculate(int etvoc)
{
    float pos = aqi_tvoc_to_level_pos(etvoc);
    if (pos <= 0.0f) {
        return BAND_AQI_TVOC[0];
    }
    if (pos >= 5.0f) {
        return BAND_AQI_TVOC[5];
    }

    int low = (int)pos;
    if (low > 4) {
        low = 4;
    }
    float frac = pos - (float)low;

    int32_t a_low  = (int32_t)BAND_AQI_TVOC[low];
    int32_t a_high = (int32_t)BAND_AQI_TVOC[low + 1];
    int32_t aqi = a_low + (int32_t)((a_high - a_low) * frac);

    if (aqi < 0) {
        aqi = 0;
    }
    if (aqi > 500) {
        aqi = 500;
    }
    return (uint16_t)aqi;
}

/**
 * @brief Startup animation - sweeps from green to red and back to green
 * 
 * This function displays a 3-second animation that smoothly transitions
 * from green to red and back to green when the device starts up.
 * Uses time-based animation to ensure accurate timing.
 */
static void startup_animation(void) {
    const uint32_t ANIMATION_DURATION_MS = 3000;  // 3 seconds total
    const uint32_t UPDATE_INTERVAL_MS = 10;  // Update every 10ms for smooth animation
    
    // Get start time in ticks
    TickType_t start_ticks = xTaskGetTickCount();
    TickType_t duration_ticks = pdMS_TO_TICKS(ANIMATION_DURATION_MS);
    
    while (1) {
        // Calculate elapsed time
        TickType_t current_ticks = xTaskGetTickCount();
        TickType_t elapsed_ticks = current_ticks - start_ticks;
        
        // Check if animation is complete
        if (elapsed_ticks >= duration_ticks) {
            break;
        }
        
        // Calculate progress from 0.0 to 1.0 based on elapsed time
        float progress = (float)elapsed_ticks / (float)duration_ticks;
        
        uint16_t hue;
        if (progress <= 0.5f) {
            // First half: green to red (0.0 to 0.5)
            float ratio = progress * 2.0f;  // 0.0 to 1.0
            hue = HUE_GREEN - (uint16_t)(ratio * HUE_GREEN);
        } else {
            // Second half: red back to green (0.5 to 1.0)
            float ratio = (progress - 0.5f) * 2.0f;  // 0.0 to 1.0
            hue = (uint16_t)(ratio * HUE_GREEN);
        }
        
        // Get color from hue (intensity is applied by LED task)
        uint32_t color = get_color_from_hue(hue);
        led_set_color(color);
        
        // Delay until next update
        vTaskDelay(pdMS_TO_TICKS(UPDATE_INTERVAL_MS));
    }
    
    // Ensure we end on green
    uint32_t final_color = get_color_from_hue(HUE_GREEN);
    led_set_color(final_color);
}

// Command processing task
void command_task(void *pvParameters)
{
    ESP_LOGI(TAG, "Command task started");
    
    while (1) {
        // Process incoming commands
        serial_process_commands();
        
        // Small delay to prevent CPU spinning
        vTaskDelay(10 / portTICK_PERIOD_MS);
    }
}

// Sensor reading task
void sensor_task(void *pvParameters)
{
    ESP_LOGI(TAG, "Sensor task started");

    esp_task_wdt_add(NULL);

    while (1) {
        esp_task_wdt_reset();

        // Read ENS210 temperature and humidity
        ens210_read_envir();
        float temp_c = ens210_get_temperature(1); // 1 = Celsius
        float humidity = ens210_get_humidity();
        uint8_t ens210_status = ens210_get_status();

        // Write AHT21 compensation data to ENS160
        uint8_t ens210_t[2];
        uint8_t ens210_h[2];
        ens210_get_envir(ens210_t, ens210_h);
        ens16x_write_ens210_data(ens210_t, ens210_h);
        
        // Refresh ENS16X device status (needed to detect warm-up completion)
        ens16x_get_device_status();
        
        // Read ENS16X air quality data
        int etvoc = ens16x_read_etvoc();
        int eco2 = ens16x_read_eco2();
        int aqi_s = ens16x_read_aqi();         // ENS161 relative AQI-S (0-500)
        int aqi = aqi_calculate(etvoc);        // Canonical AirCube VOC Level (TVOC-derived, 0-500)
        int aqi_uba = ens16x_read_aqi_uba();
        enum ENS_STATUS ens16x_status = ens16x_get_status();

        current_aqi = aqi;
        
        // Helper function to convert ENS16X status to string
        const char* ens16x_status_str;
        switch(ens16x_status) {
            case ENS_OP_OK:
                ens16x_status_str = "OK";
                break;
            case ENS_WARM_UP:
                ens16x_status_str = "Warming Up";
                break;
            case ENS_NO_VALID_OUTPUT:
                ens16x_status_str = "No Valid Output";
                break;
            case ENS_RESERVED:
                ens16x_status_str = "Reserved";
                break;
            default:
                ens16x_status_str = "Unknown";
                break;
        }
        
        // Display all sensor data with status
        ESP_LOGI(TAG, "=== Sensor Data ===");
        ESP_LOGI(TAG, "ENS210 - Status: 0x%02X, Temperature: %.2f°C, Humidity: %.2f%%",
                 ens210_status, temp_c, humidity);
        ESP_LOGI(TAG, "ENS16X - Status: %s, eTVOC: %d ppb, eCO2: %d ppm, VOC Level: %d, AQI-S: %d, AQI-UBA: %d",
                 ens16x_status_str, etvoc, eco2, aqi, aqi_s, aqi_uba);
        
        // Send sensor data as JSON over serial
        serial_send_sensor_data(ens210_status, temp_c, humidity,
                               ens16x_status_str, etvoc, eco2, aqi, aqi_s, aqi_uba);
        
        // Record sample into history accumulator and check for 10-min flush.
        // History stores the new canonical VOC Level (TVOC-derived); flushed entries
        // from before this change still hold the old AQI-S value in the same
        // columns - the on-flash byte layout did not change.
        history_record_sample(temp_c, humidity, aqi, eco2, etvoc);
        history_check_flush();
        
        // Push sensor data to Zigbee and BLE every 10 seconds
        static TickType_t last_zb_update = 0;
        TickType_t now = xTaskGetTickCount();
        if ((now - last_zb_update) >= pdMS_TO_TICKS(10000)) {
            last_zb_update = now;
            zigbee_update_sensors(temp_c, humidity, eco2, etvoc, aqi);
            ble_bthome_update(temp_c, humidity, eco2, etvoc);
        }

        // Wait for configurable period before next reading
        uint32_t period = get_sensor_readout_period_ms();
        vTaskDelay(period / portTICK_PERIOD_MS);
    }
}

void app_main(void)
{
    ESP_LOGI(TAG, "AirCube");

    ESP_LOGI(TAG, "LED color: continuous green->red from canonical VOC Level (TVOC-derived)");

    // Configure power management
    // ESP32-H2 valid max frequencies: 96, 64, or 48 MHz. Min = XTAL = 32 MHz.
    esp_pm_config_t pm_config = {
        .max_freq_mhz = 48,            // Maximum CPU frequency (MHz)
        .min_freq_mhz = 32,            // Minimum CPU frequency (XTAL, MHz)
        .light_sleep_enable = false     // Automatic light sleep when idle
    };
    
    esp_err_t ret = esp_pm_configure(&pm_config);
    if (ret != ESP_OK) {
        ESP_LOGE(TAG, "Failed to configure power management: %s", esp_err_to_name(ret));
    } else {
        ESP_LOGI(TAG, "Power management configured with automatic light sleep enabled");
    }

    // Initialize NVS (Non-Volatile Storage) for saving settings
    ret = nvs_flash_init();
    if (ret == ESP_ERR_NVS_NO_FREE_PAGES || ret == ESP_ERR_NVS_NEW_VERSION_FOUND) {
        // NVS partition was truncated and needs to be erased
        // Retry nvs_flash_init
        ESP_ERROR_CHECK(nvs_flash_erase());
        ret = nvs_flash_init();
    }
    ESP_ERROR_CHECK(ret);
    ESP_LOGI(TAG, "NVS initialized");

    // Initialize I2C driver (must be done before initializing sensors)
    if (i2c_driver_init() != ESP_OK) {
        ESP_LOGE(TAG, "Failed to initialize I2C driver");
        return;
    }

    // Create mutex for readout period
    readout_period_mutex = xSemaphoreCreateMutex();
    if (readout_period_mutex == NULL) {
        ESP_LOGE(TAG, "Failed to create readout period mutex");
        return;
    }
    
    // Initialize serial protocol
    serial_protocol_init();
    
    // Initialize LED control system
    led_init();
    
    // Set initial LED color to green (animation start color) before animation
    uint32_t start_color = get_color_from_hue(HUE_GREEN);
    led_set_color(start_color);

    
    // // Play startup animation (3 second sweep from green to red and back)
    // ESP_LOGI(TAG, "Playing startup animation");
    // startup_animation();
    
    // Initialize history module (sensor data logging to flash)
    esp_err_t hist_ret = history_init();
    if (hist_ret != ESP_OK) {
        ESP_LOGW(TAG, "History init failed: %s (continuing without history)", esp_err_to_name(hist_ret));
    }
    
    // Initialize button for brightness control
    button_init();
    
    // Initialize AHT21 temperature and humidity sensor (ENS210 API)
    ens210_init();
    ESP_LOGI(TAG, "AHT21 initialized");
    
    // Initialize ENS160 air quality sensor (ENS16X driver)
    ens16x_init();
    ESP_LOGI(TAG, "ENS160 initialized");
    
    // Initialize Zigbee stack (End Device, idles until long-press on first boot)
    zigbee_init();

    // Initialize BLE BTHome broadcaster (shares radio with Zigbee via coexistence)
    ble_bthome_init();
    
    // Create command processing task
    xTaskCreate(command_task, "command_task", COMMAND_TASK_STACK_SIZE, NULL, 
                COMMAND_TASK_PRIORITY, NULL);
    ESP_LOGI(TAG, "Command task created");
    
    // Create sensor reading task
    xTaskCreate(sensor_task, "sensor_task", SENSOR_TASK_STACK_SIZE, NULL, 
                SENSOR_TASK_PRIORITY, NULL);
    ESP_LOGI(TAG, "Sensor task created");

    // Main loop for LED color based on VOC Level (with pairing override)
    while (1) {
        vTaskDelay(pdMS_TO_TICKS(20));  // Update LED every 20ms for smooth transitions
        
        // ── Pairing mode: flash blue at 2 Hz ──
        if (zigbee_is_pairing()) {
            uint32_t tick_ms = xTaskGetTickCount() * portTICK_PERIOD_MS;
            bool on = ((tick_ms / 250) % 2) == 0;
            led_set_color(on ? LED_COLOR_BLUE : LED_COLOR_OFF);
            continue;   // Skip normal VOC Level color while pairing
        }
        
        // ── Normal mode: continuous green->red from canonical VOC Level ──
        if (current_aqi >= AQI_MAX) {
            target_hue = 0;  // Red for high VOC Level
        } else {
            target_hue = aqi_to_hue(current_aqi);
        }
        
        // Smoothly transition current_hue towards target_hue
        float hue_diff = (float)target_hue - current_hue;
        current_hue += hue_diff * TRANSITION_SPEED;
        
        // Convert current hue to color (cast to uint16_t for color conversion)
        uint32_t color = get_color_from_hue((uint16_t)current_hue);
        
        // Update LED with the smoothly transitioning color
        led_set_color(color);
    }
}

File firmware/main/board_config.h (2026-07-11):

#ifndef BOARD_CONFIG_H
#define BOARD_CONFIG_H

/*
 * ESP32-H2 SuperMini + ENS160/AHT21 breakout + external WS2812 strip
 *
 * Wiring (3.3V logic — do not use 5V on sensor or LED data):
 *   Sensor SDA  -> GPIO1
 *   Sensor SCL  -> GPIO0
 *   Sensor VCC  -> 3V3
 *   Sensor GND  -> GND
 *   LED DIN     -> GPIO4 (IO4 — breadboard pin)
 *   LED 5V      -> 5V (USB) if your strip needs 5V; level-shift data if required
 *   LED GND     -> GND
 *   Boot button -> GPIO9 (onboard, short press = brightness, hold 3s = Zigbee pair)
 */

#define I2C_MASTER_SDA_IO           1
#define I2C_MASTER_SCL_IO           0
#define LED_RMT_TX_GPIO             4
#define BUTTON_GPIO                 9

#endif

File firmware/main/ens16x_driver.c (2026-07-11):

//
// Created by glina126 on 11/8/2023.
//

#include "ens16x_driver.h"
#include "i2c_driver.h"
#include <string.h>
#include <stdbool.h>
#include "esp_log.h"

#define ENS16X_I2C_ADDRESS 0x52

// registers
#define ENS16X_DEVICE_STATUS 0x20
#define ENS16X_OPMODE 0x10
#define ENS16X_REG_DATA_ETVOC 0x22
#define ENS16X_REG_DATA_ECO2 0x24
#define ENS16X_REG_DATA_AQI_UBA 0x21
#define ENS16X_REG_DATA_AQI_S 0x26

#define ENS16X_REG_RH_IN 0x15
#define ENS16X_REG_TH_IN 0x13

#define ENS16X_REG_DATA_AQI_S 0x26

#define ENS16X_PART_ID_REG 0x00
#define ENS16X_PART_ID_ENS160 0x0160
#define ENS16X_PART_ID_ENS161 0x0161

enum ENS_OPMODE ens16x_op_mode = ENS_RESERVED;
enum ENS_STATUS ens16x_status = ENS_RESET;
uint8_t ens16x_new_data_available = 0;
uint8_t ens16x_new_gpr_available = 0;
int ens16x_tvoc = -1;
int ens16x_eco2 = -1;
int ens16x_aqi = -1;
int ens16x_aqi_uba = -1;
static bool ens16x_is_ens161 = false;


enum ENS_OPMODE ens16x_get_opmode(void);
void ens16x_set_opmode(enum ENS_OPMODE mode);

enum ENS_STATUS ens16x_get_device_status(void){

    // read in ENS16x part number
    uint8_t i2c_data[1];
    memset(i2c_data, 0, 1);
    uint8_t i2c_byte_address[] = {ENS16X_DEVICE_STATUS};
    i2c_driver_read(ENS16X_I2C_ADDRESS, i2c_byte_address, 1, i2c_data, 1);

    // bit 0 = NEWGPR
    // bit 1 = NEWDAT
    // bit 2-3 = VALIDITY FLAG (2-bit field: 0=OK, 1=WARM_UP, 2=RESERVED, 3=NO_VALID_OUTPUT)
    // bit 6 = STATER - error invalid operating mode
    // bit 7 = STATS - OPMODE is running
    ens16x_new_data_available = (i2c_data[0] & (1U << 1)) >> 1;
    ens16x_new_gpr_available = (i2c_data[0] & (1U << 0)) >> 0;
    ens16x_status = (i2c_data[0] >> 2) & 0x03;  // Extract bits 2-3 as 2-bit value

    return i2c_data[0];

}

enum ENS_OPMODE ens16x_get_opmode(void){
    uint8_t i2c_data[1];
    memset(i2c_data, 0, 1);
    uint8_t i2c_byte_address[] = {ENS16X_OPMODE};
    i2c_driver_read(ENS16X_I2C_ADDRESS, i2c_byte_address, 1, i2c_data, 1);
    return i2c_data[0];
}

void ens16x_set_opmode(enum ENS_OPMODE mode){
    uint8_t i2c_data[2];
    memset(i2c_data, 0, 2);
    i2c_data[0] = ENS16X_OPMODE;

    // transition the sensor to idle mode first
    i2c_data[1] = ENS_IDLE;
    i2c_driver_write(ENS16X_I2C_ADDRESS, i2c_data, 2);

    // transition to ENS_OPMODE
    i2c_data[1] = mode;
    i2c_driver_write(ENS16X_I2C_ADDRESS, i2c_data, 2);

    // confirm by reading
    uint8_t i2c_return_data[1];
    uint8_t reg_addr[1] = {ENS16X_OPMODE};
    i2c_driver_read(ENS16X_I2C_ADDRESS, reg_addr, 1, i2c_return_data, 1);
    ESP_LOGD("ens16x", "operational mode: %u", i2c_data[0]);
    if(i2c_return_data[0] == mode){
        ESP_LOGI("ens16x", "Mode change success");
    } else
        ESP_LOGE("ens16x", "Error changing modes");
}

int ens16x_read_etvoc(void){
    uint8_t i2c_data[2];
    memset(i2c_data, 0, 2);
    uint8_t i2c_byte_address[] = {ENS16X_REG_DATA_ETVOC};
    i2c_driver_read(ENS16X_I2C_ADDRESS, i2c_byte_address, 1, i2c_data, 2);
    uint16_t etvoc = ((uint16_t )i2c_data[0] | (uint16_t)i2c_data[1] << 8);

    ESP_LOGD("ens16x", "ETVOC_LSB: %u, ETVOC_MSB: %u", i2c_data[0], i2c_data[1]);
    ESP_LOGI("ens16x", "etvoc: %hu", etvoc);
    ens16x_tvoc = etvoc;

    return etvoc;
}

int ens16x_read_eco2(void){
    uint8_t i2c_data[2];
    memset(i2c_data, 0, 2);
    uint8_t i2c_byte_address[] = {ENS16X_REG_DATA_ECO2};
    i2c_driver_read(ENS16X_I2C_ADDRESS, i2c_byte_address, 1, i2c_data, 2);
    uint16_t eco2 = ((uint16_t )i2c_data[0] | (uint16_t)i2c_data[1] << 8);

    ESP_LOGD("ens16x", "ECO2_LSB: %u, ECO2_MSB: %u", i2c_data[0], i2c_data[1]);
    ESP_LOGI("ens16x", "eco2: %hu", eco2);
    ens16x_eco2 = eco2;

    return eco2;
}

int ens16x_read_aqi(void){
    if (!ens16x_is_ens161) {
        ens16x_aqi = -1;
        return -1;
    }

    uint8_t i2c_data[2];
    memset(i2c_data, 0, 2);
    uint8_t i2c_byte_address[] = {ENS16X_REG_DATA_AQI_S};
    i2c_driver_read(ENS16X_I2C_ADDRESS, i2c_byte_address, 1, i2c_data, 2);
    uint16_t aqi = ((uint16_t )i2c_data[0] | (uint16_t)i2c_data[1] << 8);

    ESP_LOGI("ens16x", "aqi: %hu", aqi);
    ens16x_aqi = aqi;

    return aqi;
}

int ens16x_read_aqi_uba(void){
    uint8_t i2c_data[1];
    memset(i2c_data, 0, 1);
    uint8_t i2c_byte_address[] = {ENS16X_REG_DATA_AQI_UBA};
    i2c_driver_read(ENS16X_I2C_ADDRESS, i2c_byte_address, 1, i2c_data, 1);
    int aqi_uba = i2c_data[0] & 0x07;  // AQI-UBA is in bits 0-2

    ESP_LOGI("ens16x", "aqi_uba: %d", aqi_uba);
    ens16x_aqi_uba = aqi_uba;

    return aqi_uba;
}

int ens16x_get_aqi(void){
    return ens16x_aqi;
}

int ens16x_get_aqi_uba(void){
    return ens16x_aqi_uba;
}

int ens16x_get_etvoc(void){
    return ens16x_tvoc;
}

enum ENS_STATUS ens16x_get_status(void){
    return ens16x_status;
}

void ens16x_write_ens210_data(uint8_t * t, uint8_t * h){
    // write envir compensation data to ens16x
    uint8_t i2c_data[5] = {};
    i2c_data[0] = ENS16X_REG_TH_IN;
    i2c_data[1] = t[0];
    i2c_data[2] = t[1];
    i2c_data[3] = h[0];
    i2c_data[4] = h[1];

    // write the regs
    i2c_driver_write(ENS16X_I2C_ADDRESS, i2c_data, 5);

    // read back the temperature and humidity for verification
    uint8_t address[1] = {0x30};
    i2c_data[0] = 0;
    i2c_data[1] = 0;

    i2c_driver_read(ENS16X_I2C_ADDRESS, address, 1, i2c_data, 2);

    for(int i = 0; i < 2; i++){
        ESP_LOGD("ens16x", "temperature i2c_data[%i]: %x", i, i2c_data[i]);
    }
    uint32_t temperature = ((uint32_t)i2c_data[0] | ((uint32_t)i2c_data[1]) << 8) & 0xffff;

    float TinK = (float)temperature / 64; // Temperature in Kelvin
    float TinC = TinK - 273.15; // Temperature in Celsius
    float TinF = TinC * 1.8 + 32.0; // Temperature in Fahrenheit

    ESP_LOGD("ens16x", "%5.1fK %4.1fC %4.1fF", TinK, TinC, TinF);

    // check humidity
    address[0] = 0x32;
    i2c_data[0] = 0;
    i2c_data[1] = 0;
    i2c_driver_read(ENS16X_I2C_ADDRESS, address, 1, i2c_data, 2);

    for(int i = 0; i < 2; i++){
        ESP_LOGD("ens16x", "humidity i2c_data[%i]: %x", i, i2c_data[i]);
    }

    uint32_t humidity = ((uint32_t)i2c_data[0] | ((uint32_t)i2c_data[1]) << 8) & 0xffff;
    float H = (float)humidity/512;
    ESP_LOGD("ens16x", "%2.0f%%", H);


}
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

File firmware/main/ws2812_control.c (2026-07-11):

/**
 * @file ws2812_control.c
 * @brief WS2812 LED strip control implementation
 * 
 * This file implements the low-level control for WS2812 addressable LED strips
 * using the ESP32's RMT (Remote Control) peripheral. It provides initialization
 * and data transmission functions for controlling individual LEDs in the strip.
 * 
 * @author StuckAtPrototype, LLC
 * @version 3.0
 */

#include "ws2812_control.h"
#include "driver/rmt_tx.h"
#include "esp_err.h"
#include "esp_check.h"
#include "freertos/FreeRTOS.h"
#include "esp_log.h"

// Hardware configuration
#include "board_config.h"
#define BITS_PER_LED_CMD        24  // 24 bits per LED (8 bits each for R, G, B)
#define LED_BUFFER_ITEMS        (NUM_LEDS * BITS_PER_LED_CMD)

// WS2812 timing parameters (assuming 10MHz RMT resolution)
#define T0H     3  // 0 bit high time (0.3μs)
#define T1H     6  // 1 bit high time (0.6μs)
#define T0L     8  // 0 bit low time (0.8μs)
#define T1L     5  // 1 bit low time (0.5μs)

static const char *TAG = "NeoPixel WS2812 Driver";

// Global variables for RMT control
static rmt_channel_handle_t led_chan = NULL;      // RMT channel handle
static rmt_encoder_handle_t led_encoder = NULL;   // RMT encoder handle
static uint8_t led_data_buffer[NUM_LEDS * 3];     // Buffer for LED data (3 bytes per LED: RGB)

/**
 * @brief RMT encoder wrapper function
 * 
 * This function wraps the bytes encoder for RMT transmission.
 * It's used internally by the RMT driver to encode data for transmission.
 * 
 * @param encoder RMT encoder handle
 * @param channel RMT channel handle
 * @param primary_data Data to encode
 * @param data_size Size of data to encode
 * @param ret_state Return state pointer
 * @return Number of encoded symbols
 */
static size_t ws2812_rmt_encode(rmt_encoder_t *encoder, rmt_channel_handle_t channel, const void *primary_data, size_t data_size, rmt_encode_state_t *ret_state)
{
    rmt_encoder_handle_t bytes_encoder = (rmt_encoder_handle_t)encoder;
    rmt_encode_state_t session_state = 0;
    size_t encoded_symbols = bytes_encoder->encode(bytes_encoder, channel, primary_data, data_size, &session_state);
    *ret_state = session_state;
    return encoded_symbols;
}

/**
 * @brief Initialize WS2812 LED control system
 * 
 * This function initializes the RMT (Remote Control) peripheral for controlling
 * WS2812 LED strips. It configures the RMT channel, sets up the timing parameters
 * for WS2812 protocol, and creates the necessary encoders.
 * 
 * @return ESP_OK on success, error code on failure
 */
esp_err_t ws2812_control_init(void)
{
    ESP_LOGI(TAG, "Create RMT TX channel");
    rmt_tx_channel_config_t tx_chan_config = {
            .gpio_num = LED_RMT_TX_GPIO,           // GPIO pin for LED data
            .clk_src = RMT_CLK_SRC_DEFAULT,        // Use default clock source
            .resolution_hz = 10 * 1000 * 1000,     // 10MHz resolution for precise timing
            .mem_block_symbols = 64,               // Memory block size
            .trans_queue_depth = 4,                // Transmission queue depth
    };
    ESP_RETURN_ON_ERROR(rmt_new_tx_channel(&tx_chan_config, &led_chan), TAG, "Failed to create RMT TX channel");

    ESP_LOGI(TAG, "Install led strip encoder");
    rmt_bytes_encoder_config_t bytes_encoder_config = {
            .bit0 = {
                    .level0 = 1,        // High level for '0' bit
                    .duration0 = T0H,   // High duration for '0' bit
                    .level1 = 0,        // Low level for '0' bit
                    .duration1 = T0L,   // Low duration for '0' bit
            },
            .bit1 = {
                    .level0 = 1,        // High level for '1' bit
                    .duration0 = T1H,   // High duration for '1' bit
                    .level1 = 0,        // Low level for '1' bit
                    .duration1 = T1L,   // Low duration for '1' bit
            },
            .flags.msb_first = 1,       // Send MSB first
    };
    ESP_RETURN_ON_ERROR(rmt_new_bytes_encoder(&bytes_encoder_config, &led_encoder), TAG, "Failed to create bytes encoder");

    ESP_LOGI(TAG, "Enable RMT TX channel");
    ESP_RETURN_ON_ERROR(rmt_enable(led_chan), TAG, "Failed to enable RMT channel");

    return ESP_OK;
}

/**
 * @brief Write LED data to WS2812 strip
 * 
 * This function takes a structure containing LED color data and transmits it
 * to the WS2812 LED strip using the RMT peripheral. It converts the 24-bit
 * color values to the proper byte format and sends them via RMT.
 * 
 * @param new_state Structure containing color data for all LEDs
 * @return ESP_OK on success, error code on failure
 */
esp_err_t ws2812_write_leds(struct led_state new_state)
{
    // Convert 24-bit color values to RGB byte format
    for (uint32_t led = 0; led < NUM_LEDS; led++) {
        uint32_t bits_to_send = new_state.leds[led];
        led_data_buffer[led * 3 + 0] = (bits_to_send >> 16) & 0xFF; // Red component
        led_data_buffer[led * 3 + 1] = (bits_to_send >> 8) & 0xFF;  // Green component
        led_data_buffer[led * 3 + 2] = bits_to_send & 0xFF;         // Blue component
    }

    // Configure transmission parameters
    rmt_transmit_config_t tx_config = {
            .loop_count = 0,  // No looping
    };

    // Transmit the LED data via RMT
    ESP_RETURN_ON_ERROR(rmt_transmit(led_chan, led_encoder, led_data_buffer, sizeof(led_data_buffer), &tx_config), TAG, "Failed to transmit RMT data");
    
    // Wait for transmission to complete
    ESP_RETURN_ON_ERROR(rmt_tx_wait_all_done(led_chan, portMAX_DELAY), TAG, "Failed to wait for RMT transmission to finish");

    return ESP_OK;
}

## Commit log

2026-05-11 Hardened the Zigbee end-device against rejoin flapping (5-min/10-rejoin watchdog that triggers esp_restart, backoff only resets after 60 s stable uptime, keep_alive 3 s → 7 s, default TX power 10 → 2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
    [serial_protocol.c]
2026-05-23 new color band threshold algorithm for fixed banded scheme
    [main.c]
2026-05-23 Add canonical TVOC-derived AQI (0-400) alongside legacy AQI-S.
    Wire the new AQI through serial JSON, Zigbee (attr 0x0003), history, ZHA quirk, and Z2M converter; merge publish_brightness startup brightness reporting and immediate button sync on top of dev rejoin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
2026-05-23 Hot-fix 1.5.1: single TVOC AQI on Zigbee @ 0x0002, scale 0-500, restore zigbee merge fixes
    [main.c, serial_protocol.c]
2026-05-29 Drive LED from canonical AQI gradient instead of banded eCO2+TVOC mapping.
    The LED now uses the same continuous green-to-red curve as legacy firmware, but fed by TVOC-derived AQI rather than AQI-S. Docs, HA gauge, and desktop app color thresholds are updated to match.
2026-05-29 Update LED color reference tables to match AQI-driven gradient.
    Rework the README and Home Assistant color tables around the canonical TVOC-derived AQI: color-first gradient bands (green to lime to yellow to orange to red), accurate AQI/TVOC landmarks, and a master AQI/TVOC/color table. eCO2 is documented as informational only since it no longer drives the LED.
2026-06-14 Make ZHA quirk load on Home Assistant without quirks v2
    Combine the v1 and v2 quirk definitions into a single file. Older HA releases (zigpy older than 0.65, e.g. HA 2024.1.x) have no zigpy.quirks.v2 module, so importing QuirkBuilder raised ImportError and the whole quirk failed to load. Detect quirks-v2 support and fall back to a classic v1 CustomDevice so the device still imports and is named correctly on old HA; modern HA keeps the full eCO2/tVOC/AQI sensors and Brightness number.
2026-07-11 Add AirCircle enclosure and ESP32-H2 SuperMini DIY support.
    Adapt firmware for breadboard builds with ENS160/AHT21, external WS2812,
    and board-specific pin config. Organize mechanical files into air-circle
    and original folders.
    [AirCube air wall 11-7-43.3mf, AirCube bottom_prod_12-11.step, AirCube top 20mm PROD.step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]
2026-07-11 Add enclosure assembly guide with screw sizes and mount order.
    Document soldering, M3/M2 fastener choices, and step-by-step assembly
    for the sensor module, SuperMini, LED ring, and top cover.
2026-07-12 Add visual assembly guide infographic to the repo.
    Include the step-by-step diagram in docs/ and align written assembly
    instructions with the tab, sensor, SuperMini, ring, and top cover flow.
2026-07-12 Add Printables link for AirCircle enclosure STLs.
    Link the published Printables model from the README quick links and
    the 3D-printed parts section.
